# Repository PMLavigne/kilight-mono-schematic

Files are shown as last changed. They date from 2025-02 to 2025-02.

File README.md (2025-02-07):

# KiLight Mono Schematic

The KiLight project is an open source / open hardware RGB+CCT wifi light controller system meant for use in filming environments that may be affected by the lower PWM frequencies and RF noise created by cheap off-the-shelf light controllers. KiLight is pronounced like "Key Light", get it. KiLight Mono is specifically the single-channel variant that can control a single RGB+CCT light - the project has been designed with an eye towards producing a dual-channel version as well, but that has not been built yet. 

This repository contains the circuit schematic and board layout files, if you want to build your own.

Made using [KiCad][KiCad] 8.0

[KiCad]: https://www.kicad.org/

## License

<p xmlns:cc="http://creativecommons.org/ns#" xmlns:dct="http://purl.org/dc/terms/"><a property="dct:title" rel="cc:attributionURL" href="https://github.com/PMLavigne/kilight-mono-schematic">KiLight Mono Schematics</a> by <a rel="cc:attributionURL dct:creator" property="cc:attributionName" href="https://github.com/PMLavigne">Patrick Lavigne</a> is licensed under <a href="https://creativecommons.org/licenses/by-nc-sa/4.0/?ref=chooser-v1" target="_blank" rel="license noopener noreferrer" style="display:inline-block;">CC BY-NC-SA 4.0</a></p>

This project makes use of the KiCad libraries, and may include cached copies of parts of them. The KiCad libraries are licensed under a modified Creative Commons CC-BY-SA 4.0 License, which you can read more about [here][KiCadLibraryLicense].

[KiCadLibraryLicense]: https://www.kicad.org/libraries/license/

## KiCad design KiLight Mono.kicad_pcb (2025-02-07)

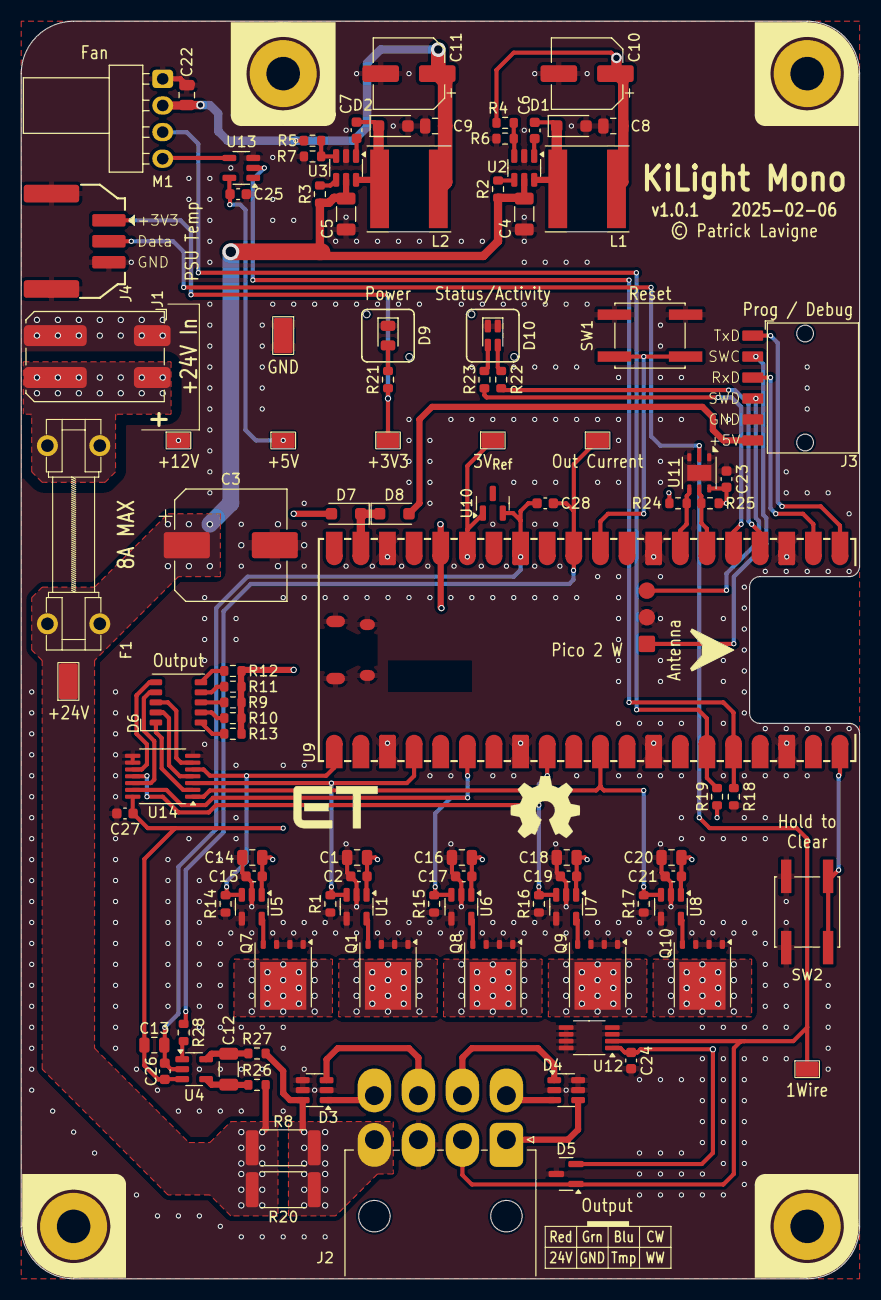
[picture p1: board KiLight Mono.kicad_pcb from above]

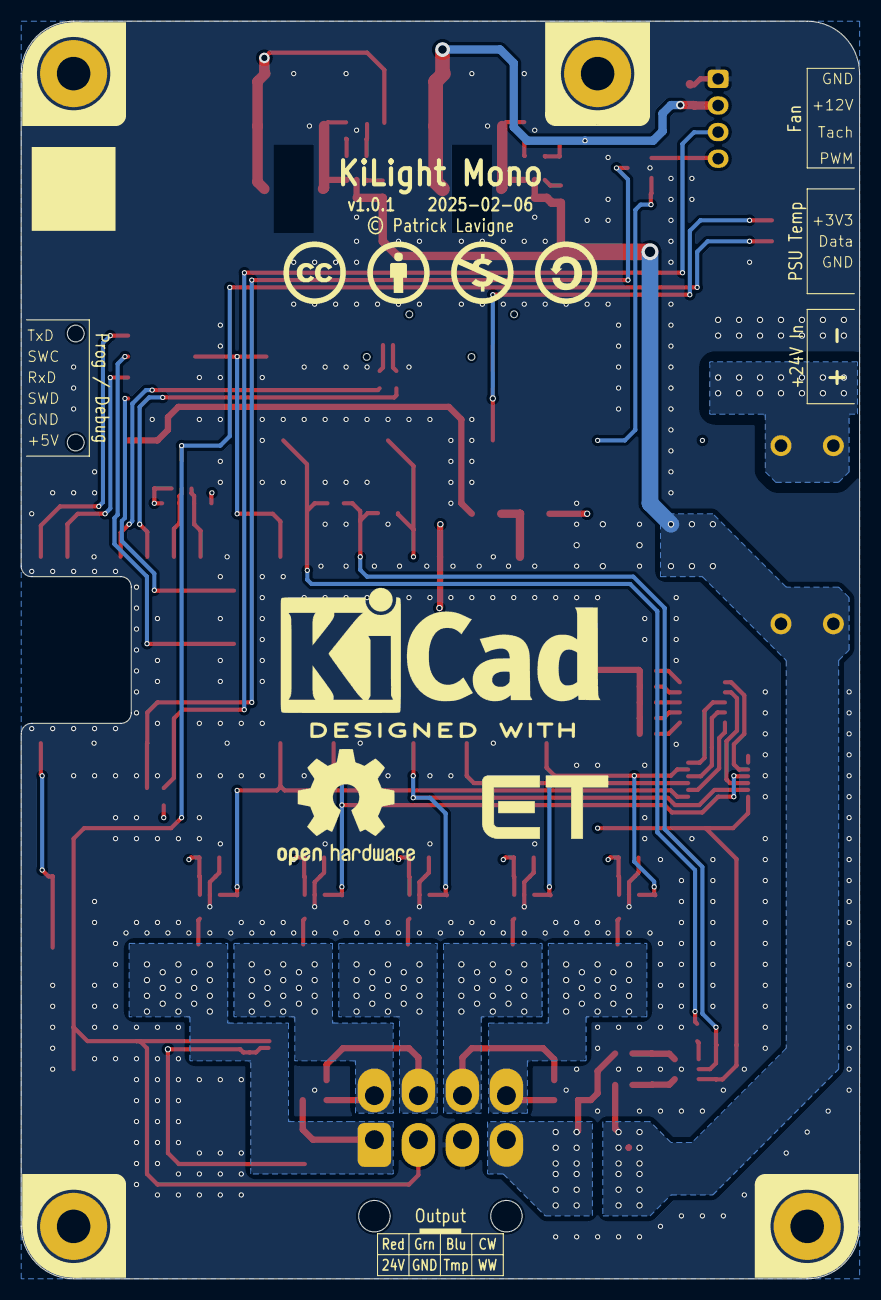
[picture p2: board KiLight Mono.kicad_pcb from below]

Board: 4 copper layers, 80.0 x 120.0 mm, 116 parts (7 on the bottom side), 65 nets.

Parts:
C1, C8, C9, C13, C14, C16, C18, C20, C22: 10uF; C_0805_2012Metric
C2, C6, C7, C15, C17, C19, C21, C23, C24, C25, C26, C27, C28: 100nF; C_0603_1608Metric
C3: 470uF; CP_Elec_10x12.5
C4, C5: 10uF; C_1206_3216Metric
C10: 100uF; CP_Elec_6.3x5.8
C11: 100uF; CP_Elec_6.3x7.7
C12: 100nF*; C_1206_3216Metric
D1, D2, D7, D8: PMEG2015EH; D_SOD-123F
D3, D4: SMS24T1G; SOT-23-6
D5: D1213A-01SO; SOT-23
D6: Output; LED_RGBCCT_5050-10
D9: Power; LED_LightPipe_Bivar-VLP_0805_2012Metric
D10: Status/Activity; LED_LightPipe_Bivar-VLP_BiColor_0805_2012Metric
F1: 8A; Fuseholder5x20_horiz_open_lateral_Type-II
H1: Hole A; MountingHole_3.2mm_M3_Pad
H2: Hole B; MountingHole_3.2mm_M3_Pad
H3: Hole C; MountingHole_3.2mm_M3_Pad
H4: Hole D; MountingHole_3.2mm_M3_Pad
ICN1: OSHW Front; OSHW-Symbol_6.7x6mm_SilkScreen
ICN2: OSHW Back; OSHW-Logo2_14.6x12mm_SilkScreen
ICN3: ET Front; Symbol_ET-Logo_8x4mm_SilkScreen
ICN4: ET Back; Symbol_ET-Logo_12x6mm_SilkScreen
ICN5: KiCad Back; KiCad-Logo2_12mm_SilkScreen
ICN6: CC Back; Symbol_CC_SilkScreenTop_6mm
ICN7: CC-BY Back; Symbol_CC_BY_SilkScreenTop_6mm
ICN8: CC-NC Back; Symbol_CC_NC_SilkScreenTop_6mm
ICN9: CC-SA Back; Symbol_CC_SA_SilkScreenTop_6mm
J1: +24V In; TerminalBlock_WAGO_2060-452_1x02_P4.00mm
J2: Output; Molex_Mini-Fit_Jr_45586-08_2x04_P4.20mm_Horizontal
J3: Prog / Debug; Amphenol_MiniTek_95000-x06_1x06_P2.0mm_Horizontal
J4: PSU Temp; Molex_DuraClik_502352-03XX_1x03-1MP-P2.00mm_SMD_Horizontal
L1: 33uH; L_Taiyo-Yuden_NR-80xx
L2: 47uH; L_Taiyo-Yuden_NR-80xx
M1: Fan; FanPinHeader_1x04_P2.54mm_THT_Horizontal
Q1, Q7, Q8, Q9, Q10: CSD18504Q5A; TDSON-8-1
R1, R2, R3, R14, R15, R16, R17, R18: 100K; R_0603_1608Metric
R4: 54.9K*; R_0603_1608Metric
R5: 147K*; R_0603_1608Metric
R6, R7, R28: 10K*; R_0603_1608Metric
R8, R20: 15m; R_2512_6332Metric
R9, R19: 2K; R_0603_1608Metric
R10, R11, R12, R13: 1K4; R_0603_1608Metric
R21, R22, R23: 1K; R_0603_1608Metric
R24, R25: 4K7; R_0603_1608Metric
R26, R27: 10*; R_0603_1608Metric
SW1: Reset; SW_SPST_EVQQ2
SW2: Hold to Clear; SW_SPST_EVQQ2
TP1: GND; TestPoint_Loop_1206_RCT_SMD
TP2: +3V3; TestPoint_Loop_0805_RCT_SMD
TP3: +5V; TestPoint_Loop_0805_RCT_SMD
TP4: +12V; TestPoint_Loop_0805_RCT_SMD
TP5: +24V; TestPoint_Loop_1206_RCT_SMD
TP6: Out Current; TestPoint_Loop_0805_RCT_SMD
TP7: 3V_{Ref}; TestPoint_Loop_0805_RCT_SMD
TP10: 1Wire; TestPoint_Loop_0805_RCT_SMD
U1, U5, U6, U7, U8: UCC27517A; SOT-23-5
U2, U3: LV2862; SOT-23-6
U4: INA281B2; SOT-23-5
U9: Pico 2 W; RPi_PicoW_SMD_NoTPs
U10: LM4040DBZ-3; SOT-23
U11: DS2485; Maxim_TDFN-6-1EP_3x3mm_P0.95mm_EP1.5x2.3mm
U12: TMP1826D; Texas_DGK0008A_VSSOP-8_3x3mm_P0.65mm
U13: 74AHCT1G04; SOT-23-5
U14: 74LVC06A; TSSOP-14_4.4x5mm_P0.65mm

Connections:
+3V3: C13.2, C23.2, C24.2, C26.2, C27.2, D5.2 (Vp), J4.1, R19.1, R21.1, R24.1, R25.1, TP2.1, U4.3 (V_{S}), U9.36 (3V3), U11.6 (V_{CC}), U12.1 (V_{DD}), U14.14 (V_{CC})
+5V: C8.1, C10.1, C25.2, D7.2 (A), L1.2, R4.2, R9.1, R10.1, R11.1, R12.1, R13.1, TP3.1, U13.5 (VCC)
+12V: C1.2, C2.2, C9.1, C11.1, C14.2, C15.2, C16.2, C17.2, C18.2, C19.2, C20.2, C21.2, C22.1, L2.2, M1.2 (+), R5.2, TP4.1, U1.1 (V_{DD}), U5.1 (V_{DD}), U6.1 (V_{DD}), U7.1 (V_{DD}), U8.1 (V_{DD})
+24V: C3.1, C4.1, C5.1, F1.2, R2.1, R3.1, R8.1, R20.1, R26.2, TP5.1, U2.5 (Vin), U3.5 (Vin)
/1Wire Data: D5.1 (CH1), J2.2, J4.2, TP10.1, U11.2 (IO), U12.2 (SDQ)
/Blue: R15.2, U6.3 (IN+), U9.6 (GPIO4), U14.13 (6A)
/CW: R16.2, U7.3 (IN+), U9.9 (GPIO6), U14.11 (5A)
/Controller/ADC V_{REF}: TP7.1, U9.35 (ADC_VREF), U10.1 (K)
/Controller/Activity LED: R22.1, U9.24 (GPIO18)
/Controller/Activity LED Anode: D10.1 (A1), R22.2
/Controller/Debug +5V: D8.2 (A), J3.6
/Controller/Debug RxD: J3.3, U9.22 (GPIO17)
/Controller/Debug TxD: J3.1, U9.21 (GPIO16)
/Controller/Fan PWM: R18.1, U9.16 (GPIO12), U13.2
/Controller/Fan Tacho: M1.3 (Tacho), R19.2, U9.15 (GPIO11)
/Controller/Fan-PWM-Out: M1.4 (PWM), U13.4
/Controller/Power LED Anode: D9.2 (A), R21.2
/Controller/SCL: R24.2, U9.27 (GPIO21), U11.4 (SCL)
/Controller/SDA: R25.2, U9.26 (GPIO20), U11.5 (SDA)
/Controller/SWCLK: J3.2, U9.D1 (SWCLK)
/Controller/SWDIO: J3.4, U9.D3 (SWDIO)
/Controller/Status LED: R23.1, U9.25 (GPIO19)
/Controller/Status LED Anode: D10.4 (A2), R23.2
/Controller/V_{SYS}: D7.1 (K), D8.1 (K), U9.39 (VSYS)
/Controller/~Clear: SW2.1, U9.20 (GPIO15)
/Controller/~RESET: SW1.1, U9.30 (RUN)
/Current: C28.1, R28.1, TP6.1, U9.31 (GPIO26_ADC0)
/Green: R1.2, U1.3 (IN+), U9.4 (GPIO2), U14.3 (2A)
/LED Drivers/+24V Out: D3.6 (Cathode), J2.4, R8.2, R20.2, R27.2
/LED Drivers/Blue Out: D4.1 (Cathode), J2.6, Q8.5 (D)
/LED Drivers/CW Out: D4.3 (Cathode), J2.5, Q9.5 (D)
/LED Drivers/Current Sense Amplifier/Filter +: C12.2, R26.1, U4.4 (IN+)
/LED Drivers/Current Sense Amplifier/Filter -: C12.1, R27.1, U4.5 (IN-)
/LED Drivers/Current Sense Amplifier/Out Current Raw: R28.2, U4.1 (OUT)
/LED Drivers/Green Out: D3.3 (Cathode), J2.7, Q1.5 (D)
/LED Drivers/LED Driver 1/Driver Gate: Q7.4 (G), U5.5 (OUT)
/LED Drivers/LED Driver 2/Driver Gate: Q1.4 (G), U1.5 (OUT)
/LED Drivers/LED Driver 3/Driver Gate: Q8.4 (G), U6.5 (OUT)
/LED Drivers/LED Driver 4/Driver Gate: Q9.4 (G), U7.5 (OUT)
/LED Drivers/LED Driver 5/Driver Gate: Q10.4 (G), U8.5 (OUT)
/LED Drivers/Output Indicator/Blue Anode: D6.9 (BA), R11.2
/LED Drivers/Output Indicator/Blue Cathode: D6.2 (BK), U14.12 (6Y)
/LED Drivers/Output Indicator/CW Anode: D6.10 (CWA), R12.2
/LED Drivers/Output Indicator/CW Cathode: D6.1 (CWK), U14.10 (5Y)
/LED Drivers/Output Indicator/Green Anode: D6.7 (GA), R10.2
/LED Drivers/Output Indicator/Green Cathode: D6.4 (GK), U14.4 (2Y)
/LED Drivers/Output Indicator/Red Anode: D6.8 (RA), R9.2
/LED Drivers/Output Indicator/Red Cathode: D6.3 (RK), U14.6 (3Y)
/LED Drivers/Output Indicator/WW Anode: D6.6 (WWA), R13.2
/LED Drivers/Output Indicator/WW Cathode: D6.5 (WWK), U14.2 (1Y)
/LED Drivers/Red Out: D3.1 (Cathode), J2.8, Q7.5 (D)
/LED Drivers/WW Out: D4.4 (Cathode), J2.1, Q10.5 (D)
/Power Supply/+24V Raw: F1.1, J1.2
/Power Supply/Voltage Rails/5V Buck Boot: C6.1, U2.1 (CB)
/Power Supply/Voltage Rails/5V Buck Feedback: R4.1, R6.1, U2.3 (FB)
/Power Supply/Voltage Rails/5V Buck Switch: C6.2, D1.1 (K), L1.1, U2.6 (SW)
/Power Supply/Voltage Rails/5V Enable: R2.2, U2.4 (~SHDN)
/Power Supply/Voltage Rails/12V Buck Boot: C7.1, U3.1 (CB)
/Power Supply/Voltage Rails/12V Buck Feedback: R5.1, R7.2, U3.3 (FB)
/Power Supply/Voltage Rails/12V Buck Switch: C7.2, D2.1 (K), L2.1, U3.6 (SW)
/Power Supply/Voltage Rails/12V Enable: R3.2, U3.4 (~SHDN)
/Red: R14.2, U5.3 (IN+), U9.1 (GPIO0), U14.5 (3A)
/WW: R17.2, U8.3 (IN+), U9.11 (GPIO8), U14.1 (1A)
GND: C1.1, C2.1, C3.2, C4.2, C5.2, C8.2, C9.2, C10.2, C11.2, C14.1, C15.1, C16.1, C17.1, C18.1, C19.1, C20.1, C21.1, C22.2, C23.1, C24.1, C25.1, C27.1, D1.2 (A), D2.2 (A), D3.2 (CommonAnode), D3.4 (Cathode), D3.5 (CommonAnode), D4.2 (CommonAnode), D4.5 (CommonAnode), D4.6 (Cathode), D5.3 (Vn), D9.1 (K), D10.2 (K1), D10.3 (K2), H1.1, H2.1, H3.1, H4.1, J1.1, J2.3, J3.5, J4.3, J4.MP (MountPin), M1.1 (-), Q1.1 (S), Q1.2 (S), Q1.3 (S), Q7.1 (S), Q7.2 (S), Q7.3 (S), Q8.1 (S), Q8.2 (S), Q8.3 (S), Q9.1 (S), Q9.2 (S), Q9.3 (S), Q10.1 (S), Q10.2 (S), Q10.3 (S), R1.1, R6.2, R7.1, R14.1, R15.1, R16.1, R17.1, R18.2, SW1.2, SW2.2, TP1.1, U1.2 (GND), U1.4 (IN-), U2.2 (GND), U3.2 (GND), U5.2 (GND), U5.4 (IN-), U6.2 (GND), U6.4 (IN-), U7.2 (GND), U7.4 (IN-), U8.2 (GND), U8.4 (IN-), U9.3 (GND), U9.8 (GND), U9.13 (GND), U9.18 (GND), U9.23 (GND), U9.28 (GND), U9.38 (GND), U9.D2 (GND), U9.MP (USB_Shield), U11.1 (GPIO), U11.3 (GND), U11.7 (GND), U12.3 (ADDR), U12.4 (GND), U12.5 (IO3), U12.6 (IO0), U12.7 (IO1), U12.8 (IO2), U13.3 (GND), U14.7 (GND), U14.8 (4Y), U14.9 (4A)
GNDA: C13.1, C26.1, C28.2, U4.2 (GND), U9.33 (AGND), U10.2 (A)

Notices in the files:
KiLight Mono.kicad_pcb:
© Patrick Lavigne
